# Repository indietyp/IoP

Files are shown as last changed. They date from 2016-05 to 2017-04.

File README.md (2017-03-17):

# Internet of Plants
## milestones for IoP development

- [x] add slave mode
- [x] use esp8266 module
- [x] change registration to active in frontend
- [x] add global settings layout
- [x] extend mesh_network + rest_api
- [x] add water pump
- [ ] rewrite setup with frontend, instead of CLI
- [ ] installation guide
- [ ] documentation

## What is Internet of Plants?
----

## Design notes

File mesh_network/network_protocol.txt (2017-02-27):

<INIT, [PLANT_UUID, MESSAGE_UUID], [PRIORITY, RECIPIENT_UUID], [CODE], [MESSAGE, MESSAGE, MESSAGE, MESSAGE], END>

MODE
  1       [ALIVE][PING][MASTER]
    1       [ASK]
    2       [RESPONSE TO ALIVE]
  2       [DELIVER][SLAVE]
    1       [REQUEST]
    2       [SEND]
  3       [REGISTER][MASTER]
    1       [ASK PUBLICKEY]
    2       [GENERATE PUBLICKEY]
    3       [SAVE AND SEND AES][ENCRYPTED]
    4       [SAVE AND SEND OK]
    5       [ESTABLISH WEBSERVER][ENCRYPTED]
    6       [DOWNLOAD][ENCRYPTED]
    7       [CANCEL WEBSERVER AND TEST REST]
    8       [SEND DONE]
    9       [SEND DONE]
    95      [SUCCESS]
    98      [RECORD ALREADY EXISTS]
    99      [FAIL]
  4       [DISCOVER][MASTER][SLAVE]
    1       [INITIAL]
    2       [RESPONSE][NOT REGISTERED][MASTER]
    3       [RESPONSE][REGISTERED]    [MASTER]
    4       [RESPONSE][NOT REGISTERED][SLAVE]
    5       [RESPONSE][REGISTERED]    [SLAVE]
  5       [NOTIFY]
    1       [NEW_DATA]  - [A_MESSAGE - UUID sensor]
    2       [IP]
    3       [CHANGE]    - [A_MESSAGE - OBJECT, B_MESSAGE - UUID, C_MESSAGE - ADDITIONAL DATA]
  6       [REGISTER][LITE][SLAVE]
    1       [REQUEST][MASTER]
    2       [CHECK][SLAVE]
    3       [SEND GENERATED UUID AND CREATE OBJECT][MASTER]
    4       [CHECK AND CONFIRM][SLAVE]
    5       [SPREAD TO OTHERS][MASTER]
  7       [UPDATE][SLAVE]
    1       [SLEEP] - [START, STOP]
    2       [HOST CHANGE] - [UUID, IP]
    3       [RANGE] - [MIN, MAX]
    4       [CHANGE IP]
  8       [REMOVE]
    1       [MASTER]
      1       [ASK TOKEN][ACQUIRE LOCK] (add file with token & selected mode, also TARGET)
      2       [GENERATE AND SEND TOKEN][LOCKING TO UUID AND IP]
      3       [GENERATE AND SEND PUBLICKEY][TO]
      4       [SEND PUBLICKEY]
      5       [ASK TOKEN][CR][TO]
      6       [GENERATE AND SEND TOKEN][CR]
      7       [GENERATE PORT AND LISTEN][CR][TO]
      8       [ESTABLISH PORT AND LISTEN][CR][PO]
      9       [ASK TOKEN][SELECTED MODE][TARGET][CR][PO][TO]
      10      [GENERATE AND SEND TOKEN][CR][PO]
      11      [PURGE/DEACTIVATE INSTRUCTION][CR][PO][TO]
      12      [CONFIRMATION][CR][PO][TO]
      13      [REMOVE RELEVANT DATA][ADD TO PURGED](send to other plants)(cleanup)
    2      [SLAVE]
      1       [ASK TOKEN AND SELECTED MODE][ACQUIRE LOCK][M]
      2       [GENERATE AND SEND TOKEN][LOCKING TO UUID AND IP IF MASTER][S]
      3       [PURGE INSTRUCTION][M][TO]
      4       [CONFIRMATION][S]
      5       [ASK TOKEN][M][TO]
      6       [GENERATE AND SEND TOKEN][S]
      7       [PURGE/DEACTIVATE INSTRUCTION/CONFIRMATION][MODE (0, 1)][M][TO]
      8       [CONFIRMATION][S]
      9       [REMOVE RELEVANT DATA][ADD TO PURGED](send to other plants)

    (CR - encrypted, TO - token used, PO - alternative port used)
  9       [NO FUNCTION ASSIGNED]
(mode in CODE ex. alive: 10100 response: 10200)

SLAVE INCLUDED
  1       [ALIVE]
  2       [DELIVER]
  4       [DISCOVER]
  6       [REGISTER][LITE]
  7       [UPDATE]
  8       [REMOVE][SLAVE]

SEND LOCAL RETURN
  [MODE, CODE]
  MODE
    1 - 9  [SPECIFIED ABOVE]
  CODE
    1      [SUCESS]
    254    [FAIL - NO RESPONSE]
    255    [FAIL - PROCESS]

INIT + END
  0       [ORIGIN = SLAVE]
  1       [ORIGIN = MASTER]

PLANT_UUID
  UUID4   [SENDER UUID]
  (same across devices)

MESSAGE_UUID
  UUID4   [LOGGING]
  (same scross devices)

PRIORITY
  0 - 255 [HIGHER MORE PRIORITY]

RECIPIENT_UUID
  UUID4   [PLANT RECEIVER]
  (same across devices)

CODE
  5 DIGIT [INTEGER]
    1 DIGIT [ref. MODE]
    2 DIGIT [SUBMODE]
    2 DIGIT [SUBSUBMODE]

A_MESSAGE
  255CHAR [EXTRA INFORMATION]

B_MESSAGE
  255CHAR [EXTRA INFORMATION]

C_MESSAGE
  255CHAR [EXTRA INFORMATION]

D_MESSAGE
  255CHAR [EXTRA INFORMATION]

NOTIFY CHANGE OBJECTS
  0 - Plant
  1 - Sensor
  2 - Person
  3 - Day Night Time
  4 - Message
  5 - Host
  6 - Plant Satisfaction Level
  7 - Slave Host Change

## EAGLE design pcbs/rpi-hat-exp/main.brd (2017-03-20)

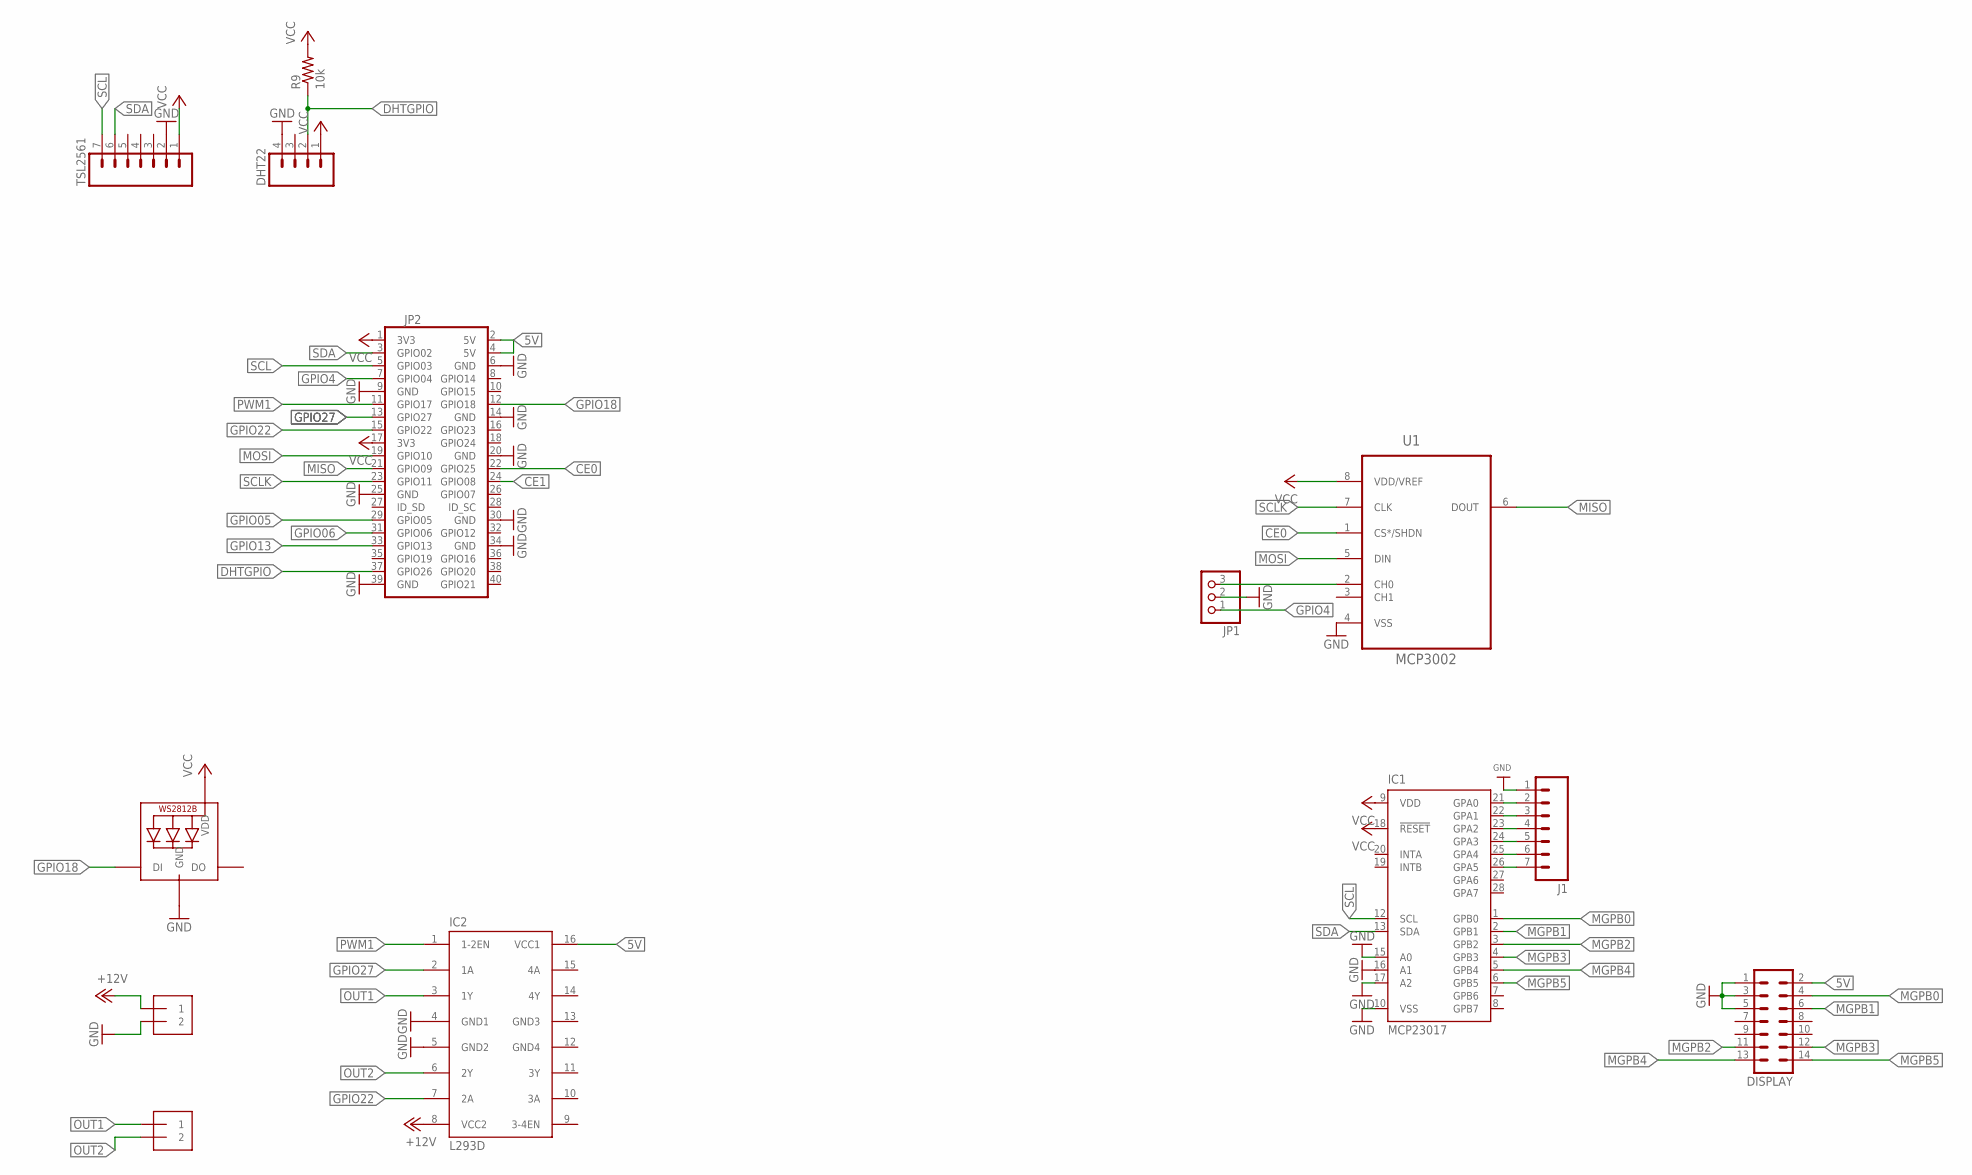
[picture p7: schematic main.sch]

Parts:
DHT22: M041X04_NO_SILK; 1X04_NO_SILK
DISPLAY: MA07-2
IC1: MCP23017; DIL28-3-ROUND
IC2: L293D; DIL16
J1: M07; 1X07
J2, J3: 1X2-3.5MM
JP1: PINHD-1X3; 1X03
JP2: 40W_PI_HAT_TPH; 2X20
LED2: WS2812BTH; LED5MMRGB
R9: 10k; 0204/7
TSL2561: M07NO_SILK; 1X07_NO_SILK
U1: MCP3002; DIP254P762X533-8

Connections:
5V: DISPLAY.2, IC2.16 (VCC1), JP2.2 (5V), JP2.4 (5V)
+12V: IC2.8 (VCC2), J2.1
CE0: JP2.22 (GPIO25), U1.1 (CS*/SHDN)
CE1: JP2.24 (GPIO08)
DHTGPIO: DHT22.2, JP2.37 (GPIO26), R9.1
GND: DHT22.4, DISPLAY.1, DISPLAY.3, DISPLAY.5, IC1.10 (VSS), IC1.15 (A0), IC1.16 (A1), IC1.17 (A2), IC2.4 (GND1), IC2.5 (GND2), J1.1, J2.2, JP1.2, JP2.6 (GND), JP2.9 (GND), JP2.14 (GND), JP2.20 (GND), JP2.25 (GND), JP2.30 (GND), JP2.34 (GND), JP2.39 (GND), LED2.2 (GND), TSL2561.2, U1.4 (VSS)
GND3: IC2.13 (GND3)
GND4: IC2.12 (GND4)
GPIO4: JP1.1, JP2.7 (GPIO04)
GPIO05: JP2.29 (GPIO05)
GPIO06: JP2.31 (GPIO06)
GPIO13: JP2.33 (GPIO13)
GPIO18: JP2.12 (GPIO18), LED2.4 (DI)
GPIO22: IC2.7 (2A), JP2.15 (GPIO22)
GPIO27: IC2.2 (1A), JP2.13 (GPIO27)
MGPB0: DISPLAY.4, IC1.1 (GPB0)
MGPB1: DISPLAY.6, IC1.2 (GPB1)
MGPB2: DISPLAY.11, IC1.3 (GPB2)
MGPB3: DISPLAY.12, IC1.4 (GPB3)
MGPB4: DISPLAY.13, IC1.5 (GPB4)
MGPB5: DISPLAY.14, IC1.6 (GPB5)
MISO: JP2.21 (GPIO09), U1.6 (DOUT)
MOSI: JP2.19 (GPIO10), U1.5 (DIN)
unnamed: IC1.26 (GPA5), J1.7
unnamed: IC1.25 (GPA4), J1.6
unnamed: IC1.24 (GPA3), J1.5
unnamed: IC1.23 (GPA2), J1.4
unnamed: IC1.22 (GPA1), J1.3
unnamed: JP1.3, U1.2 (CH0)
unnamed: IC1.21 (GPA0), J1.2
OUT1: IC2.3 (1Y), J3.1
OUT2: IC2.6 (2Y), J3.2
PWM1: IC2.1 (1-2EN), JP2.11 (GPIO17)
SCL: IC1.12 (SCL), JP2.5 (GPIO03), TSL2561.7
SCLK: JP2.23 (GPIO11), U1.7 (CLK)
SDA: IC1.13 (SDA), JP2.3 (GPIO02), TSL2561.6
VCC: DHT22.1, IC1.9 (VDD), IC1.18 (!RESET), JP2.1 (3V3), JP2.17 (3V3), LED2.3 (VDD), R9.2, TSL2561.1, U1.8 (VDD/VREF)

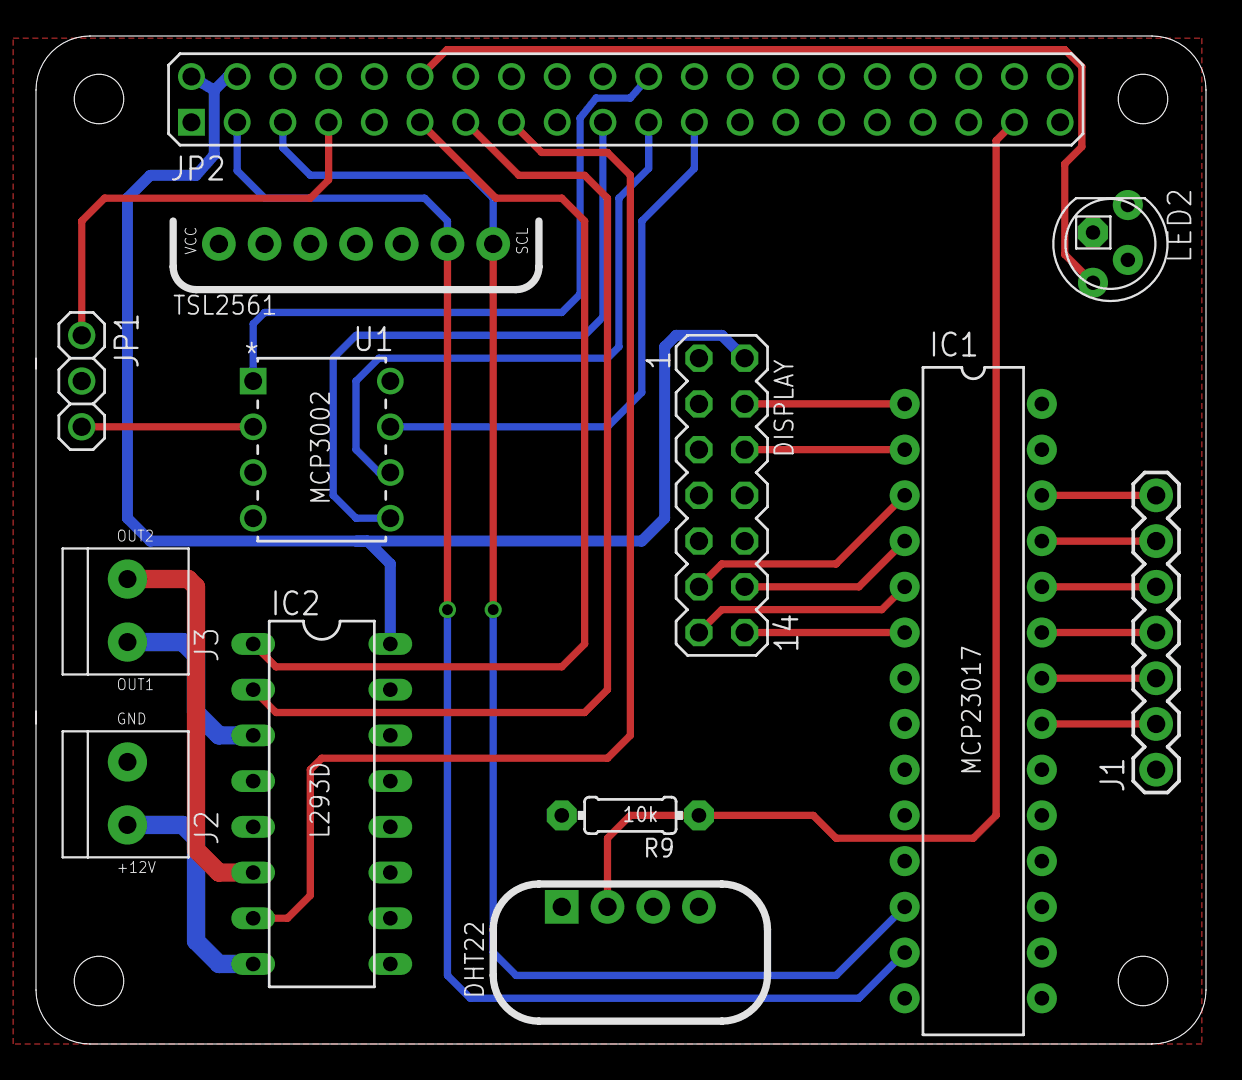
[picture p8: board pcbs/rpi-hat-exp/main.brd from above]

Board: 2 copper layers, 65.0 x 56.0 mm, 14 parts (0 on the bottom side), 31 nets.

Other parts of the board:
U$3: PI_HAT_STANDARD_TPH

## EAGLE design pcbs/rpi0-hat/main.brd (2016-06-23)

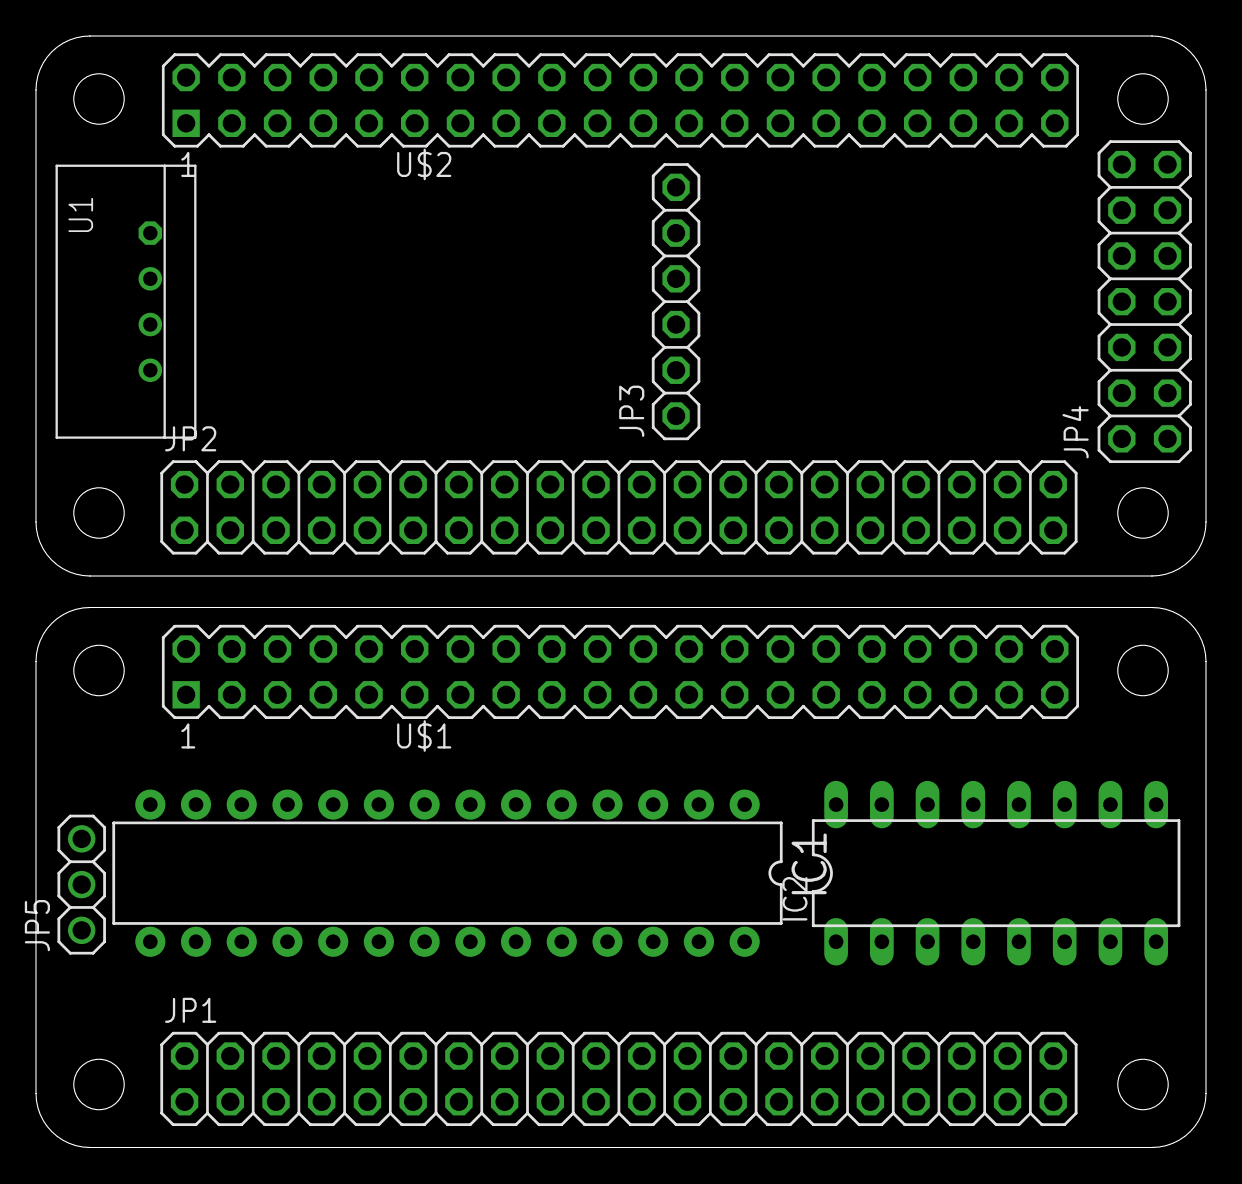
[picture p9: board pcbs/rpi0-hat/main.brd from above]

Board: 2 copper layers, 65.0 x 61.8 mm, 10 parts (0 on the bottom side), 2 nets, no tracks yet.

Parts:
IC1: MCP23017SP2; DIL28-3-ROUND
IC2: MCP3008; DIL16
JP1, JP2: 2X20
JP3: 1X06
JP4: 2X07
JP5: 1X03
U1: RHT03_DHT-22
U$1, U$2: PIZERO_THROUGH_HOLE; PIZERO_THOUGH_HOLE

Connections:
GND: IC2.9, U1.GND
VDD: IC1.9, IC2.16, U1.VDD

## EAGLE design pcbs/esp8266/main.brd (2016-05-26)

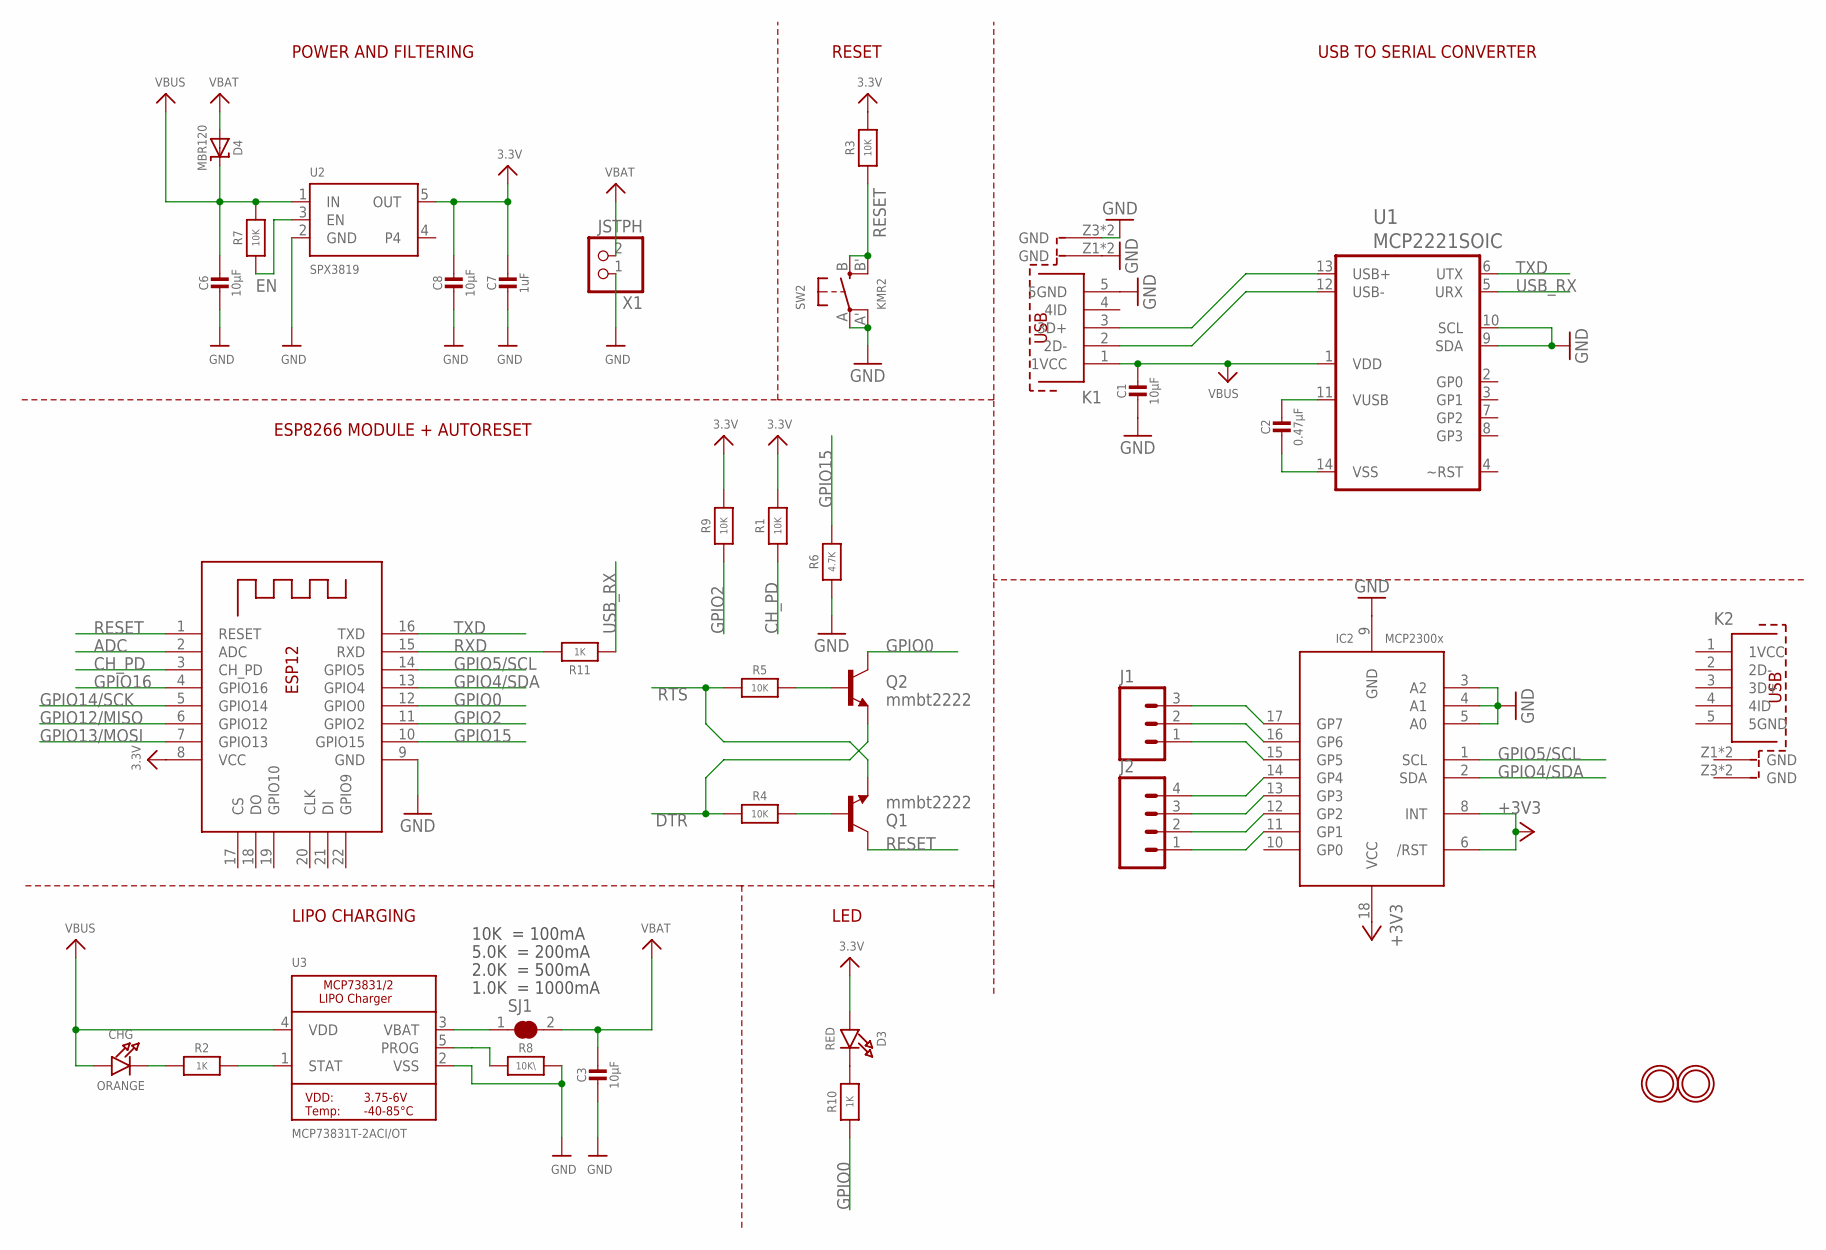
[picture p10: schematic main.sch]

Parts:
C1, C3, C6, C8: 10µF; 0805-NO
C2: 0.47µF; 0805-NO
C7: 1uF; 0603-NO
CHG: ORANGE; CHIPLED_0805_NOOUTLINE
D3: RED; CHIPLED_0805_NOOUTLINE
D4: MBR120; SOD-123
IC2: MCP23008/SO; SO18W
J1: M031X03_NO_SILK; 1X03_NO_SILK
J2: M04NO_SILK_ALL_ROUND; 1X04_NO_SILK_ALL_ROUND
K1, K2: 629105150521
Q1, Q2: mmbt2222; SOT23-3
R1, R3, R4, R7, R9: 10K; 0603-NO
R2, R10: 1K; 0603-NO
R5: 10K; _0603MP
R6: 4.7K; 0603-NO
R8: 10K\; 0603-NO
R11: 1K; _0603MP
SJ1: SOLDERJUMPER_CLOSED; SOLDERJUMPER_CLOSEDWIRE
SW2: KMR2; BTN_KMR2_4.6X2.8
U1: MCP2221SOIC; SOIC14
U2: SPX3819; SOT23-5
U3: MCP73831T-2ACI/OT; SOT23-5
U$31, U$32: MOUNTINGHOLE2.5; MOUNTINGHOLE_2.5_PLATED
X1: JSTPH; JSTPH2
X2: ESP-12; ESP-12E

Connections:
3.3V: C7.1, C8.1, D3.A, R1.2, R3.2, R9.2, U2.5 (OUT), X2.8 (VCC)
+3V3: IC2.6 (/RST), IC2.8 (INT), IC2.18 (VCC)
ADC: X2.2 (ADC)
CH_PD: R1.1, X2.3 (CH_PD)
DTR: Q2.2 (E), R4.1
EN: R7.1, U2.3 (EN)
GND: C1.2, C3.2, C6.2, C7.2, C8.2, IC2.3 (A2), IC2.4 (A1), IC2.5 (A0), IC2.9 (GND), K1.5 (5GND), K1.Z1 (GND), K1.Z2 (GND), K1.Z3 (GND), K1.Z4 (GND), R6.1, R8.2, SW2.A, SW2.A' (P1), U1.9 (SDA), U1.10 (SCL), U2.2 (GND), U3.2 (VSS), X1.1, X2.9 (GND)
GPIO0: Q2.3 (C), R10.1, X2.12 (GPIO0)
GPIO2: R9.1, X2.11 (GPIO2)
GPIO4/SDA: IC2.2 (SDA), X2.13 (GPIO4)
GPIO5/SCL: IC2.1 (SCL), X2.14 (GPIO5)
GPIO12/MISO: X2.6 (GPIO12)
GPIO13/MOSI: X2.7 (GPIO13)
GPIO14/SCK: X2.5 (GPIO14)
GPIO15: R6.2, X2.10 (GPIO15)
GPIO16: X2.4 (GPIO16)
unnamed: CHG.C, R2.1
unnamed: C2.1, U1.11 (VUSB)
unnamed: R2.2, U3.1 (STAT)
unnamed: R8.1, U3.5 (PROG)
unnamed: D3.C, R10.2
unnamed: C2.2, U1.14 (VSS)
unnamed: SJ1.1, U3.3 (VBAT)
unnamed: K1.3 (3D+), U1.13 (USB+)
unnamed: IC2.17 (GP7), J1.3
unnamed: IC2.16 (GP6), J1.2
unnamed: IC2.15 (GP5), J1.1
unnamed: Q1.1 (B), R4.2
unnamed: Q2.1 (B), R5.2
unnamed: IC2.14 (GP4), J2.4
unnamed: IC2.13 (GP3), J2.3
unnamed: IC2.12 (GP2), J2.2
unnamed: IC2.11 (GP1), J2.1
unnamed: K1.2 (2D-), U1.12 (USB-)
RESET: Q1.3 (C), R3.1, SW2.B (S), SW2.B' (S1), X2.1 (RESET)
RTS: Q1.2 (E), R5.1
RXD: R11.2, X2.15 (RXD)
TXD: U1.6 (UTX), X2.16 (TXD)
USB_RX: R11.1, U1.5 (URX)
VBAT: C3.1, D4.A, SJ1.2, X1.2
VBUS: C1.1, C6.1, CHG.A, D4.C, K1.1 (1VCC), R7.2, U1.1 (VDD), U2.1 (IN), U3.4 (VDD)

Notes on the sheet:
POWER AND FILTERING
RESET
10K = 100mA
5.0K = 200mA
2.0K = 500mA
1.0K = 1000mA
USB TO SERIAL CONVERTER
LIPO CHARGING
LED
ESP8266 MODULE + AUTORESET

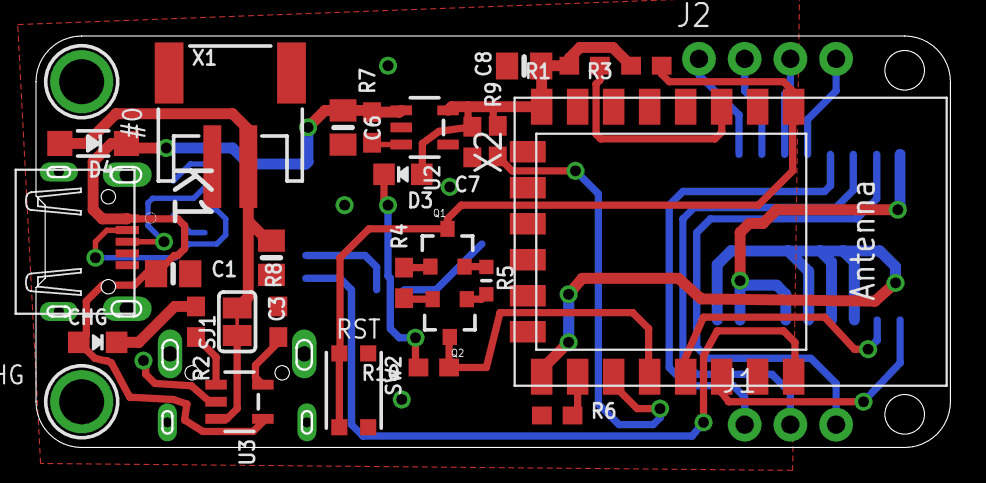
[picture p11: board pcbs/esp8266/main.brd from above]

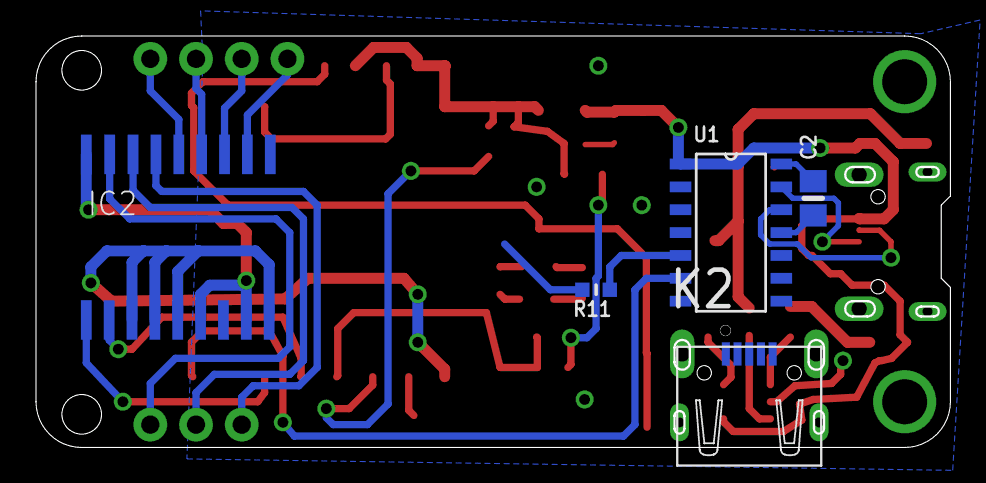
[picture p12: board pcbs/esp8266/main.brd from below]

Board: 2 copper layers, 50.8 x 22.9 mm, 36 parts (5 on the bottom side), 36 nets.

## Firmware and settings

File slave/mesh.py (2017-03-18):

import os
import json
import socket
import ubinascii
EXTERNAL_PORT = 4012
MULTICAST_ADDRESS = '224.0.0.1'


class MeshString(str):
  import sys

  def reverse(self):
    self = ''.join(list(reversed(self)))
    return self

  def rreplace(self, old, new, maxcount=sys.maxsize):
    """ reverse replace
        reverses string and runs replace at reversed old and new
        returns reversed reversed string
    """
    old = MeshString(old)
    new = MeshString(new)
    self = self.reverse().replace(old.reverse(), new.reverse(), maxcount)
    self = MeshString(self).reverse()
    return self


class MeshTools:
  def __init__(self):
    pass

  def random_string(self, length, digits=False, custom=''):
    alphabet = 'ABCDEFGHIJKLMNOPQRSTUVWXYZ'
    alphabet += '0123456789' if digits is True else ''
    alphabet += custom

    output = ''
    for _ in range(0, length):
      pointer = len(alphabet)
      while pointer >= len(alphabet):
        pointer = int(ubinascii.hexlify(os.urandom(1)), 16)
      output += alphabet[pointer]

    return output


class MeshNetwork(object):
  """ response daemon for mesh network """

  def __init__(self):
    import network
    sta_if = network.WLAN(network.STA_IF)
    self.IP = sta_if.ifconfig()[0]

  def verification(self, message, received):
    passthrough = False
    raw = received[0]

    if (raw[0] != '<' or
        raw[-1] != '>' or
        len(message) != 6 or
        len(message[1]) != 2 or
        len(message[2]) != 2 or
        len(message[3]) != 1 or
        len(message[4]) != 4 or
        len(str(message[3][0])) != 5 or
        not str(message[3][0]).isdigit() or
        message[0] not in [0, 1] or
        message[0] != message[5] or
        not str(message[2][0]).isdigit() or
        message[2][0] > 255):

      print('potential spoofing attack - no valid package')
      return False

    if 'config.json' in os.listdir():
      with open('config.json', 'r') as out:
        config = json.loads(out.read())

      if config['master']['uuid'] == message[1][0] and config['master']['ip'] == received[1][0]:
        passthrough = True
      elif str(message[3][0])[0] in ['4', '6']:
        passthrough = True

    return passthrough

  def daemon_process(self, received):
    message = received[0].decode('utf-8')
    print('received following package: \n' + message)
    message = message.replace('<', '[').replace('>', ']')
    message = eval(message)

    passthrough = self.verification(message, received)
    if self.IP != received[1][0] and passthrough:
      code = str(message[3][0])
      if code[0] == '1':
        if int(code[1:3]) == 1:
          target = [message[1][0], received[1][0]]
          self.alive(target, 2, additional_information=message[4][0])
      elif code[0] == '2':
        target = [message[1][0], received[1][0]]
        self.slave(mode=int(code[1:3]) + 1, target=target, messages=message[4])
      elif code[0] == '4':
        if int(code[1:3]) == 1:
          self.discover(target=[message[1][0], received[1][0]], mode=2)
      elif code[0] == '6':
        target = [message[1][0], received[1][0]]
        local = message[2][1]
        self.register_lite(mode=int(code[1:3]) + 1, target=target, messages=message[4], local=local)
      elif code[0] == '7':
        target = [message[1][0], received[1][0]]
        self.slave_update(mode=int(code[1:3]), sub=int(code[3:]) + 1, target=target, messages=message[4])
      elif code[0] == '8':
        target = [message[1][0], received[1][0]]
        self.remove(int(code[1:3]), int(code[3:]) + 1, target, messages=message[4])
    else:
      print('not processing request - same ip')

  def ip32bit(self, target):
    import ustruct
    return ustruct.pack('4B', *(int(x) for x in target.split('.')))

  def daemon(self):
    print('started')
    client = socket.socket(socket.AF_INET, socket.SOCK_DGRAM)
    port = EXTERNAL_PORT

    client.setsockopt(socket.SOL_SOCKET, socket.SO_REUSEADDR, 1)

    client.bind(('', port))
    while True:
      try:
        received = client.recvfrom(2048)
        self.daemon_process(received)
      except KeyboardInterrupt:
        break
      except Exception as e:
        print(e)

  def send_local(self, mode, code, port=2311):
    """ method for communication between daemon and other scripts """
    sender = socket.socket(socket.AF_INET, socket.SOCK_DGRAM)
    sender.sendto(str([mode, code]).encode(), ('127.0.0.1', port))
    sender.close()

  def send(self, code, plant=True, messages=[], master=False, priority=255,
           recipient=None, multicast=False, no_database=False, local_uuid=None):
    """ main method for sending information in the mesh_network
        code - 5 digit number for mode
        plant - optional (origin, plant object)
        messages - 4len array with additional information to be sended
                  -> auto cut to 4 existing
        master - mode of sended information - currently only Master supportet
        priority - 0-255 higher mor priority (not implemented fully yet)
        recipient - [str with UUID, ip] or peewee plant object or None if multicast
        multicast - sending with multicast
        no_database - function does not use database
    """
    configured = plant
    if configured and 'config.json' in os.listdir():
      with open('config.json') as out:
        plant = json.loads(out.read())
    else:
      configured = False

    if type(recipient) == list:
      recipient_uuid = recipient[0]
      external_address = recipient[1]
    elif recipient is None:
      recipient_uuid = ''
      external_address = ''
    else:
      recipient_uuid = str(recipient.uuid)
      external_address = recipient.ip

    len_message = len(messages)
    [messages.append('') for _ in range(0, 4 - len_message) if len_message < 4]
    [messages.pop() for _ in range(0, len_message - 4) if len_message > 4]

    messages = [x if x != '' else '-' * 256 for x in messages]

    master = int(master)
    package = [master, [], [], [], [], master]

    if configured:
      package[1].append(plant['uuid'])
    elif local_uuid is not None:
      package[1].append(local_uuid)
    else:
      package[1].append('')

    package[1].append('')

    package[2].append(priority)
    package[2].append(recipient_uuid)
    package[3].append(code)
    package[4] = messages

    package = '<' + repr(package)[1:-1] + '>'
    # package = repr(package).replace('[', '<', 1)
    # package = MeshString(package).rreplace(']', '>', 1).encode('utf-8')
    print('sending following package: \n' + package)
    package = package.encode()

    if multicast is False:
      print('package destination: ' + external_address)
      address = external_address
      sender = socket.socket(socket.AF_INET, socket.SOCK_DGRAM)
    else:
      print('package destination: multicast ({})'.format(MULTICAST_ADDRESS))
      address = MULTICAST_ADDRESS
      sender = socket.socket(socket.AF_INET, socket.SOCK_DGRAM, socket.IPPROTO_UDP)
      sender.setsockopt(socket.IPPROTO_IP, socket.IP_MULTICAST_TTL, 2)

    sender.sendto(package, (address, EXTERNAL_PORT))

    sender.close()

  def alive(self, target, mode=1, additional_information=''):
    if mode > 2:
      raise ValueError('invalid mode')

    if mode == 1:
      code = 10100
    elif mode == 2:
      code = 10200

    self.send(code, recipient=target, messages=[additional_information])

  def discover(self, target=None, mode=1):
    """ if mode is 1 - target == peewee plant object
        if mode is 2 - target == list [UUID, IP]
    """
    if mode == 1:
      print('not supported in slave module')
    elif mode == 2:
      if 'config.json' not in os.listdir():
        print('discovered - slave not registered')
        code = 40400
        self.send(code, plant=False, recipient=target, messages=['NOT_LOGGED', 'NOT_CONFIGURED', 'SLAVE'])
      else:
        print('discovered - slave registered')
        code = 40500
        self.send(code, recipient=target, messages=['NOT_LOGGED', 'CONFIGURED', 'SLAVE'])

  def slave(self, target=None, mode=2, messages=[]):
    print(target)
    print(messages)
    print(mode)

    if mode != 2:
      print('mode not supported')
    else:
      if 'config.json' in os.listdir():
        with open('config.json', 'r') as out:
          config = json.loads(out.read())
        print(config)

        if target[0] == config['master']['uuid']:
          code = 20200

          if messages[0] == 'moisture':
            from sensor import measure
            current = measure()

            self.send(code, recipient=target, messages=[current, messages[0]])

  def register_lite(self, target=None, mode=1, messages=[], local=None):
    if mode == 2:
      if 'config.json' not in os.listdir():
        code = 60200
        self.send(code, recipient=target, plant=False, local_uuid=local)
    elif mode == 4:
      code = 60400
      with open('config.json', 'w') as out:
        out.write(json.dumps({'uuid': messages[2],
                              'master': {
                                  'ip': messages[1],
                                  'uuid': messages[0]}
                              }))
      self.send(code, recipient=target)

  def slave_update(self, mode=1, sub=1, target=None, messages=[]):
    if mode > 3:
      print('mode currently not supported')
    elif mode in [1, 3]:
      if sub != 2:
        print('not supported sub mode')
      elif sub == 2:
        entry = 'sleep' if mode == 1 else 'range'
        raw = 70002
        code = raw + (mode * 100)

        with open('config.json', 'r') as out:
          config = json.loads(out.read())
          config[entry] = {}
          config[entry]['min'] = messages[0]
          config[entry]['max'] = messages[1]

        with open('config.json', 'w') as out:
          out.write(json.dumps(config))

        self.send(code, recipient=target)
    elif mode in [2]:
      if sub != 2:
        print('not supported sub mode')
      else:
        code = 70202

        with open('config.json', 'r') as out:
          config = json.loads(out.read())

        if config['master']['uuid'] == target[0] and config['master']['ip'] == target[1]:
          config['master']['uuid'] = messages[0]
          config['master']['ip'] = messages[1]

          with open('config.json', 'w') as out:
            out.write(json.dumps(config))

          self.send(code, recipient=target)

          import machine
          machine.reset()
    elif mode in [4]:
      if sub != 2:
        print('not supported sub mode')
      else:
        code = 70402

        with open('config.json', 'r') as out:
          config = json.loads(out.read())

        if config['master']['uuid'] == target[0]:
          changed = True if config['master']['ip'] != target[1] else False
          config['master']['ip'] = target[1]

          with open('config.json', 'w') as out:
            out.write(json.dumps(config))

          self.send(code, recipient=target, messages=[changed])

  def remove(self, mode, sub, target, messages=[]):
    if mode == 2:
      if sub == 2:
        with open('config.json', 'r') as out:
          config = json.loads(out.read())

        print(target)
        if config['master']['ip'] == target[1] and config['master']['uuid'] == target[0]:
          token = MeshTools().random_string(100)
          information = {'token': token}

          with open('transaction.json', 'w') as out:
            out.write(json.dumps(information))

          self.send(80202, recipient=target, messages=[token])

      elif sub == 4:
        with open('config.json', 'r') as out:
          config = json.loads(out.read())

        with open('transaction.json', 'r') as out:
          information = json.loads(out.read())

        if config['master']['ip'] == target[1] and config['master']['uuid'] == target[0] and information['token'] == messages[0]:
          information['mode'] = 'remove'

          with open('transaction.json', 'w') as out:
            out.write(json.dumps(information))

          self.send(80204, recipient=target)

      elif sub == 6:
        with open('config.json', 'r') as out:
          config = json.loads(out.read())

        with open('transaction.json', 'r') as out:
          information = json.loads(out.read())

        if config['master']['ip'] == target[1] and config['master']['uuid'] == target[0] and information['token'] == messages[0]:
          information['token'] = MeshTools().random_string(100)

          with open('transaction.json', 'w') as out:
            out.write(json.dumps(information))

          self.send(80206, recipient=target, messages=[information['token']])

      elif sub == 8:
        with open('config.json', 'r') as out:
          config = json.loads(out.read())

        with open('transaction.json', 'r') as out:
          information = json.loads(out.read())

        if config['master']['ip'] == target[1] and config['master']['uuid'] == target[0] and information['token'] == messages[0]:
          import machine
          import os

          os.remove('config.json')
          os.remove('credentials.json')
          os.remove('transaction.json')
          machine.reset()

          self.send(80208, recipient=target)


if __name__ == '__main__':
  MeshNetwork().daemon()

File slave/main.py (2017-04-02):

import network
from communication import CommunicationMainFrame
sta_if = network.WLAN(network.STA_IF)
ap_if = network.WLAN(network.AP_IF)


communication = CommunicationMainFrame()
communication.daemon(wifi=False)
# if sta_if.active():
#   communication.daemon(http=False, dns=False)
# elif ap_if.active():
#   communication.daemon(iop=False, multicast=False)

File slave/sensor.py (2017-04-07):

def measure():
  from machine import Pin, I2C
  from time import sleep
  import ntptime
  import time
  import ubinascii
  import ustruct
  import json

  ntptime.settime()

  with open('config.json', 'r') as out:
    config = json.loads(out.read())

  if 'sleep' in config:
    start = int(config['sleep']['min']) / 100
    stop = int(config['sleep']['max']) / 100
    led = True if start <= time.localtime()[3] <= stop else False
  else:
    led = True

  if 'range' in config:
    rng = config['range']
  else:
    rng = {'min': 60, 'max': 80}

  i2c = I2C(scl=Pin(5), sda=Pin(4), freq=100000)
  address = 0x20

  median = []

  alert = Pin(12, Pin.OUT)
  green = Pin(13, Pin.OUT)
  red = Pin(15, Pin.OUT)

  if led:
    alert.value(1)

  for i in range(6):
    result = i2c.readfrom_mem(address, 0, 2)
    result = ustruct.pack('>1h', *ustruct.unpack('<1h', result))
    median.append(int(ubinascii.hexlify(result).decode(), 16) / 65535 * 100)  # 2 bytes - max value == 65535
    sleep(0.5)

  alert.value(0)
  median = sum(median) / len(median)
  if median >= rng['min'] and median <= rng['max']:
    if led:
      green.value(1)
    else:
      green.value(0)

    red.value(0)
  else:
    green.value(0)

    if led:
      red.value(1)
    else:
      red.value(0)

  print(median)
  return median

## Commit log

2016-03-19 inserted protocol correctly
2016-03-21 fixed and added general status leds
    [dht.py, general.py, main.py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]
2016-03-25 bug fixes, partly finished testcase
    [main.py]
2016-05-26 moved sensor_scripts
2016-05-26 added pcbs and frontend
    [main.brd, main.sch]
2016-06-08 fixed pie chart, minor changes, css -> less, extended single page functionality
    [general.py]
2016-06-15 sensor + overview now full functionality, next settings!
2016-06-23 added concept rpi0-hat, completed plant_settings, added forecast
    [main.brd, main.sch]
2016-06-24 significant time change forecast
    [main.sch]
2016-08-18 big changes are coming, redesign database and reworking
    [dht.py, mailer.py, main.py]
2016-12-17 testing insert database
2016-12-17 database day nicht time fix
    [display.py]
2016-12-17 something seems to be wrong with the i2c handling in moisture bar
    [tsl2561.py]
2016-12-21 too many inserts fix!
2016-12-26 added simulated pi stage to production todo list and no database improvement
2016-12-28 added speedup and fixes
    [main.py]
2016-12-29 added debug defaul and changes insert to proper handling
2016-12-29 first draft - needs rework - simulated
    [main.py]
2017-01-02 w/o testing sensor improvements - now time dependent
2017-01-25 retrieve and insert slave data
2017-01-25 added dedicated & sensor integration
2017-01-30 sensor fix
2017-03-07 board changes
    [main.brd, main.sch]
2017-03-07 board changes & template init finished
    [main.brd]
2017-03-13 great changes, like the great wall of china
    [_main.brd, main.brd, main.sch]
2017-03-13 pin change
2017-03-17 I changed 'some' stuff
    [main.brd, main.sch]
2017-03-17 pump change wuhu $ board finalised
    [main.brd, main.sch]
2017-03-18 disabled water pump
2017-03-20 slave changes
    [main.brd]
2017-04-07 REST v4.1.0.1
    staged not official release yet

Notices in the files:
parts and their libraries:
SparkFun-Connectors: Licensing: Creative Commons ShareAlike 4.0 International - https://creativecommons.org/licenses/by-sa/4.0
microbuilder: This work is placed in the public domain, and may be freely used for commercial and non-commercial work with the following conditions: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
